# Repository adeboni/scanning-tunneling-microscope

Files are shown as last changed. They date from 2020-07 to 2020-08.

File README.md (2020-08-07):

# Home-made scanning tunneling microscope

This repository contains schematics I made in order to fully build Dan Berard's STM implementation, based on John Alexander's STM design: https://dberard.com/home-built-stm/

## Sample scan from the STM:
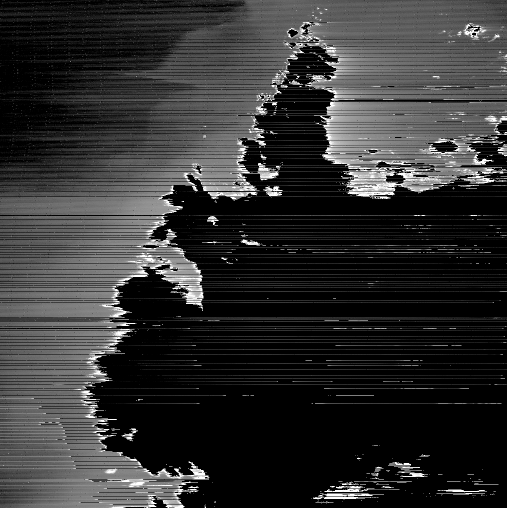
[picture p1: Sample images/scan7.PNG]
Sample scan


## Pictures of the STM:
Device photo 1
Device photo 2

## SEM image of the probe tip:
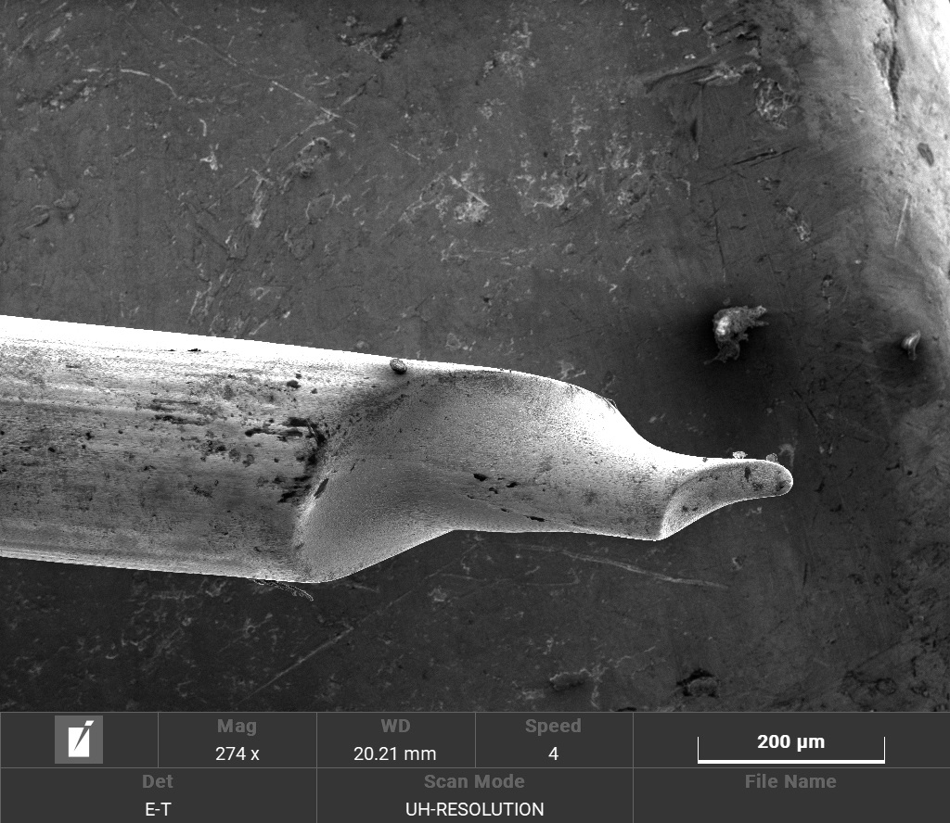
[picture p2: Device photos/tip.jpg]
Tip


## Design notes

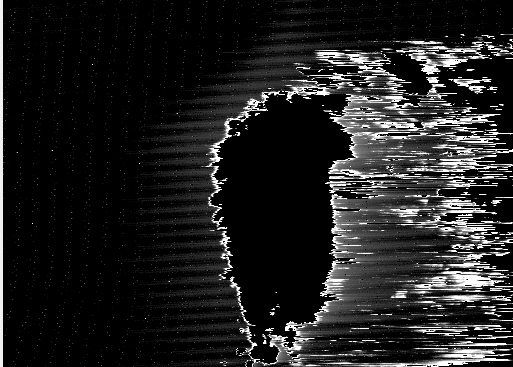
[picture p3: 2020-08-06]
Sample images/scan4.PNG

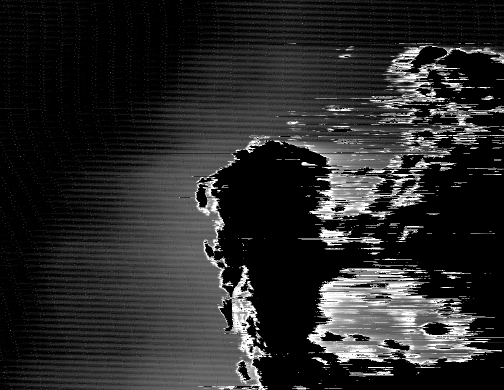
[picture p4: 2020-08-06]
Sample images/scan5.PNG

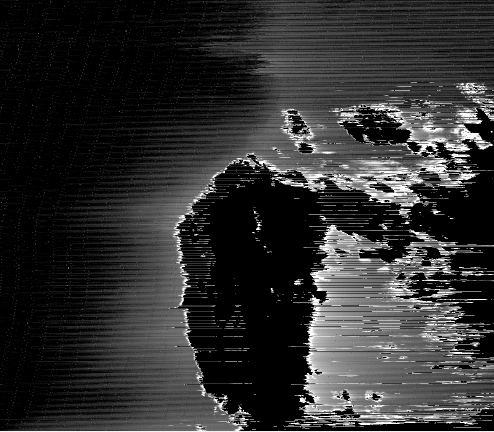
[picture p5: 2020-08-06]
Sample images/scan6.PNG

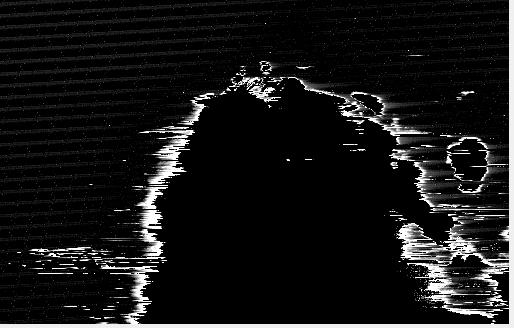
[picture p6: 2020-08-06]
Sample images/scan3.PNG

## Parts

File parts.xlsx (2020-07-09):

Qty | Part | Value | Package | Unit Cost | Total Cost
Microcontroller Board
1 | PCB |  |  | $2.00 | $2.00
1 | Teensy 3.2 |  |  | $15.00 | $15.00
2 | Pin Socket | 1x7 |  | $3.00 | $6.00
1 | 2x13 IDC Connector |  |  | $3.00 | $3.00
2 | LED |  | 5mm | $0.20 | $0.40
2 | Resistor | 120 | Axial | $0.10 | $0.20
Power Supply
1 | PCB |  |  | $2.00 | $2.00
1 | Barrel Jack |  | 2.1mm | $0.40 | $0.40
1 | Linear Regulator | 7815 | TO220 | $2.50 | $2.50
1 | Linear Regulator | 7915 | TO220 | $2.50 | $2.50
1 | Linear Regulator | LM1117-3.3 | TO220 | $2.50 | $2.50
1 | Switching Regulator | R-78E5.0-0.5 | WE78 | $2.50 | $2.50
6 | Rectifier Diode | 1N4004 | Axial | $0.20 | $1.20
4 | Electrolytic Capacitor | 3300u | Radial 18mm | $2.00 | $8.00
2 | Electrolytic Capacitor | 10u | Radial 6mm | $0.20 | $0.40
8 | Ceramic Capacitor | 1u | Radial 2.5mm | $0.60 | $4.80
2 | Resistor | 2.4k | Axial | $0.20 | $0.40
1 | Pin Header | 1x5 |  | $0.20 | $0.20
1 | AC-AC Adapter | 15VAC |  | $15.00 | $15.00
1 | Enclosure |  |  | $10.00 | $10.00
Transimpedance Amplifier
1 | PCB |  |  | $2.00 | $2.00
2 | Tantalum Capacitor | 4.7u | 2512 | $2.50 | $5.00
2 | Ceramic Capacitor | 100n | 0805 | $0.10 | $0.20
1 | Op Amp | OPA124 | SOIC8 | $15.00 | $15.00
1 | Teflon Standoff | Keystone 11301 |  | $2.00 | $2.00
1 | Resistor | 100M | Axial | $5.00 | $5.00
1 | Resistor | 220 | 0805 | $0.10 | $0.10
Analog Board
1 | PCB |  |  | $7.00 | $7.00
1 | Tantalum Capacitor | 100u | 7343 | $2.50 | $2.50
9 | Tantalum Capacitor | 10u | 3528 | $0.50 | $4.50
6 | Tantalum Capacitor | 10u | 0805 | $0.50 | $3.00
33 | Ceramic Capacitor | 100n | 0805 | $0.10 | $3.30
10 | Ceramic Capacitor | 4.7n | 0805 | $0.20 | $2.00
1 | Ceramic Capacitor | 2.2u | 1206 | $0.30 | $0.30
8 | Ceramic Capacitor | 3.3n | 0805 | $0.10 | $0.80
1 | Ceramic Capacitor | 47u | 1210 | $1.00 | $1.00
1 | LED |  | 0805 | $0.20 | $0.20
2 | DB9 Board Connector | Female | Through-hole | $3.00 | $6.00
2 | DB9 Cable Connector | Male |  | $1.50 | $3.00
4 | Ferrite Bead | 600 ohm | 0805 | $0.30 | $1.20
1 | 2x13 IDC Connector |  |  | $3.00 | $3.00
1 | 2x13 IDC Cable |  |  | $5.00 | $5.00
1 | Pin Header | 1x5 |  | $0.20 | $0.20
23 | Resistor | 3k | 0805 | $0.10 | $2.30
1 | Resistor | 1k | 0805 | $0.10 | $0.10
4 | Resistor | 220 | 0805 | $0.10 | $0.40
4 | Resistor | 1.5k | 0805 | $0.10 | $0.40
2 | Resistor | 10k | 0805 | $0.10 | $0.20
1 | Resistor | 30k | 0805 | $0.10 | $0.10
4 | Resistor | 470 | 0805 | $0.10 | $0.40
1 | Resistor | 100 | 0805 | $0.10 | $0.10
3 | Op Amp | OPA2227U | SOIC8 | $10.00 | $30.00
1 | Voltage Reference | REF102AU | SOIC8 | $6.00 | $6.00
2 | Op Amp | OPA4227 | SOIC14 | $12.00 | $24.00
1 | DAC | DAC8814 | SSOP28 | $40.00 | $40.00
1 | ADC | LTC2326 | MSOP16 | $33.00 | $33.00
1 | Op Amp | LT1469 | SOIC8 | $15.00 | $15.00
1 | Enclosure |  |  | $15.00 | $15.00
Scan Head
1 | Piezo | 6.3Khz | 20mm | $0.70 | $0.70
1 | Sapphire Crystal | 16mm |  | $7.00 | $7.00
1 | Tungsten Wire Roll | 30 AWG |  | $10.00 | $10.00
1 | Aluminum Standoff |  | 3mm x 10mm | $0.50 | $0.50
3 | Fine Adjustment Screws | 1/4-80 |  | $9.00 | $27.00
3 | Bushings | 1/4-80 |  | $9.00 | $27.00
2 | Aluminum Block |  | 0.5" x 2" x 2" | $2.00 | $4.00
4 | Screw |  | 0.5" long | $0.10 | $0.40
2 | Spring |  | 1" long | $0.50 | $1.00
1 | Copper Tape |  |  | $10.00 | $10.00
1 | Pin Header | 1x5 |  | $0.20 | $0.20
1 | Enameled Wire | 40 AWG |  | $10.00 | $10.00
2 | Neodymium magnet |  | 10mm | $0.50 | $1.00
Anti-Vibration Base
3 | Extension Springs |  | 2 ft long | $5.00 | $15.00
1 | MDF Board |  | 2 ft x 2 ft | $10.00 | $10.00
3 | Round Steel Plate |  | 0.5" x 5" | $7.00 | $21.00
1 | Round Aluminum Plate |  | 0.5" x 6" | $20.00 | $20.00
3 | Viton FKM O-Rings |  |  | $2.00 | $6.00
12 | Hard Drive Magnets |  |  | $0.50 | $6.00
3 | Eye Bolts | 3/8" | 5" long | $2.00 | $6.00
3 | Eye Bolts | 3/8" | 1" long | $2.00 | $6.00
3 | Threaded Rod | 3/8" | 3 ft long | $4.00 | $12.00
3 | Rubber Feet Stickers |  | 5mm | $0.50 | $1.50
21 | Nuts | 3/8" |  | $0.10 | $2.10
 |  |  |  | Total | $522.70

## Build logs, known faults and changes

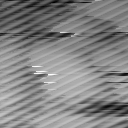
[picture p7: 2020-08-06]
Dan Berard's stuff/PC software/STM/bin/Debug/scan.tiff

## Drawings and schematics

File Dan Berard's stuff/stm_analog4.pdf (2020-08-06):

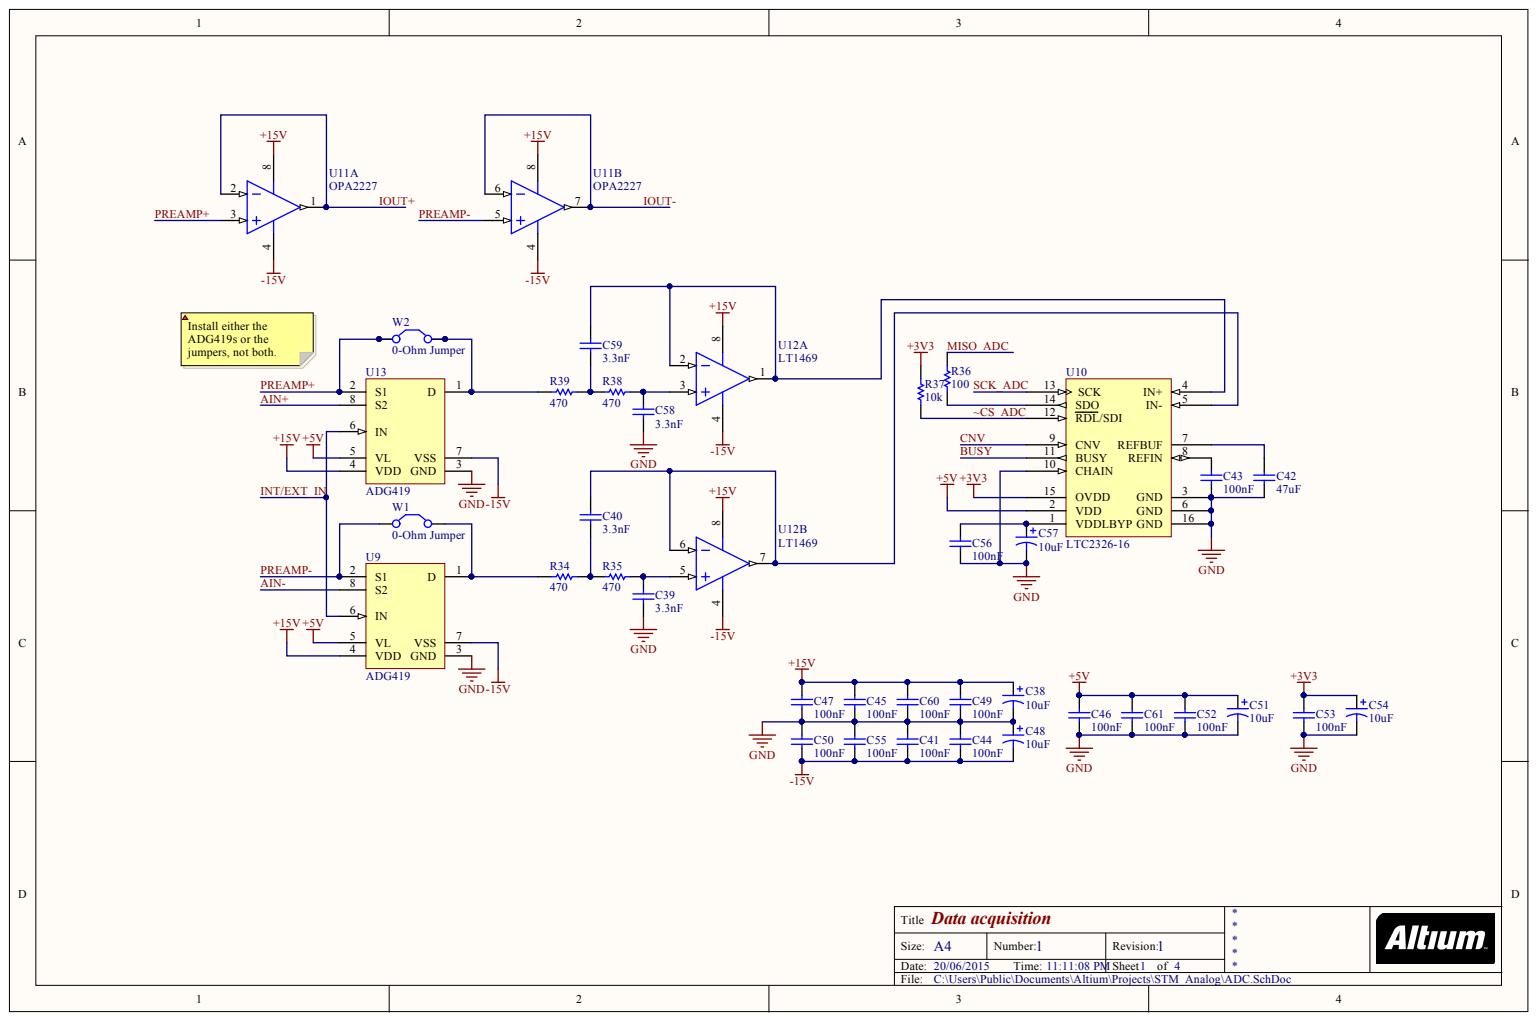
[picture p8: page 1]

Data acquisition Title | * * * * *

Size: A4 | Number: 1 | Revision: 1
Date: 20/06/2015 Time: 11:11:08 PM | | Sheet of 4

C:\Users\Public\Documents\Altium\Projects\STM_Analog\ADC.SchDoc
File:

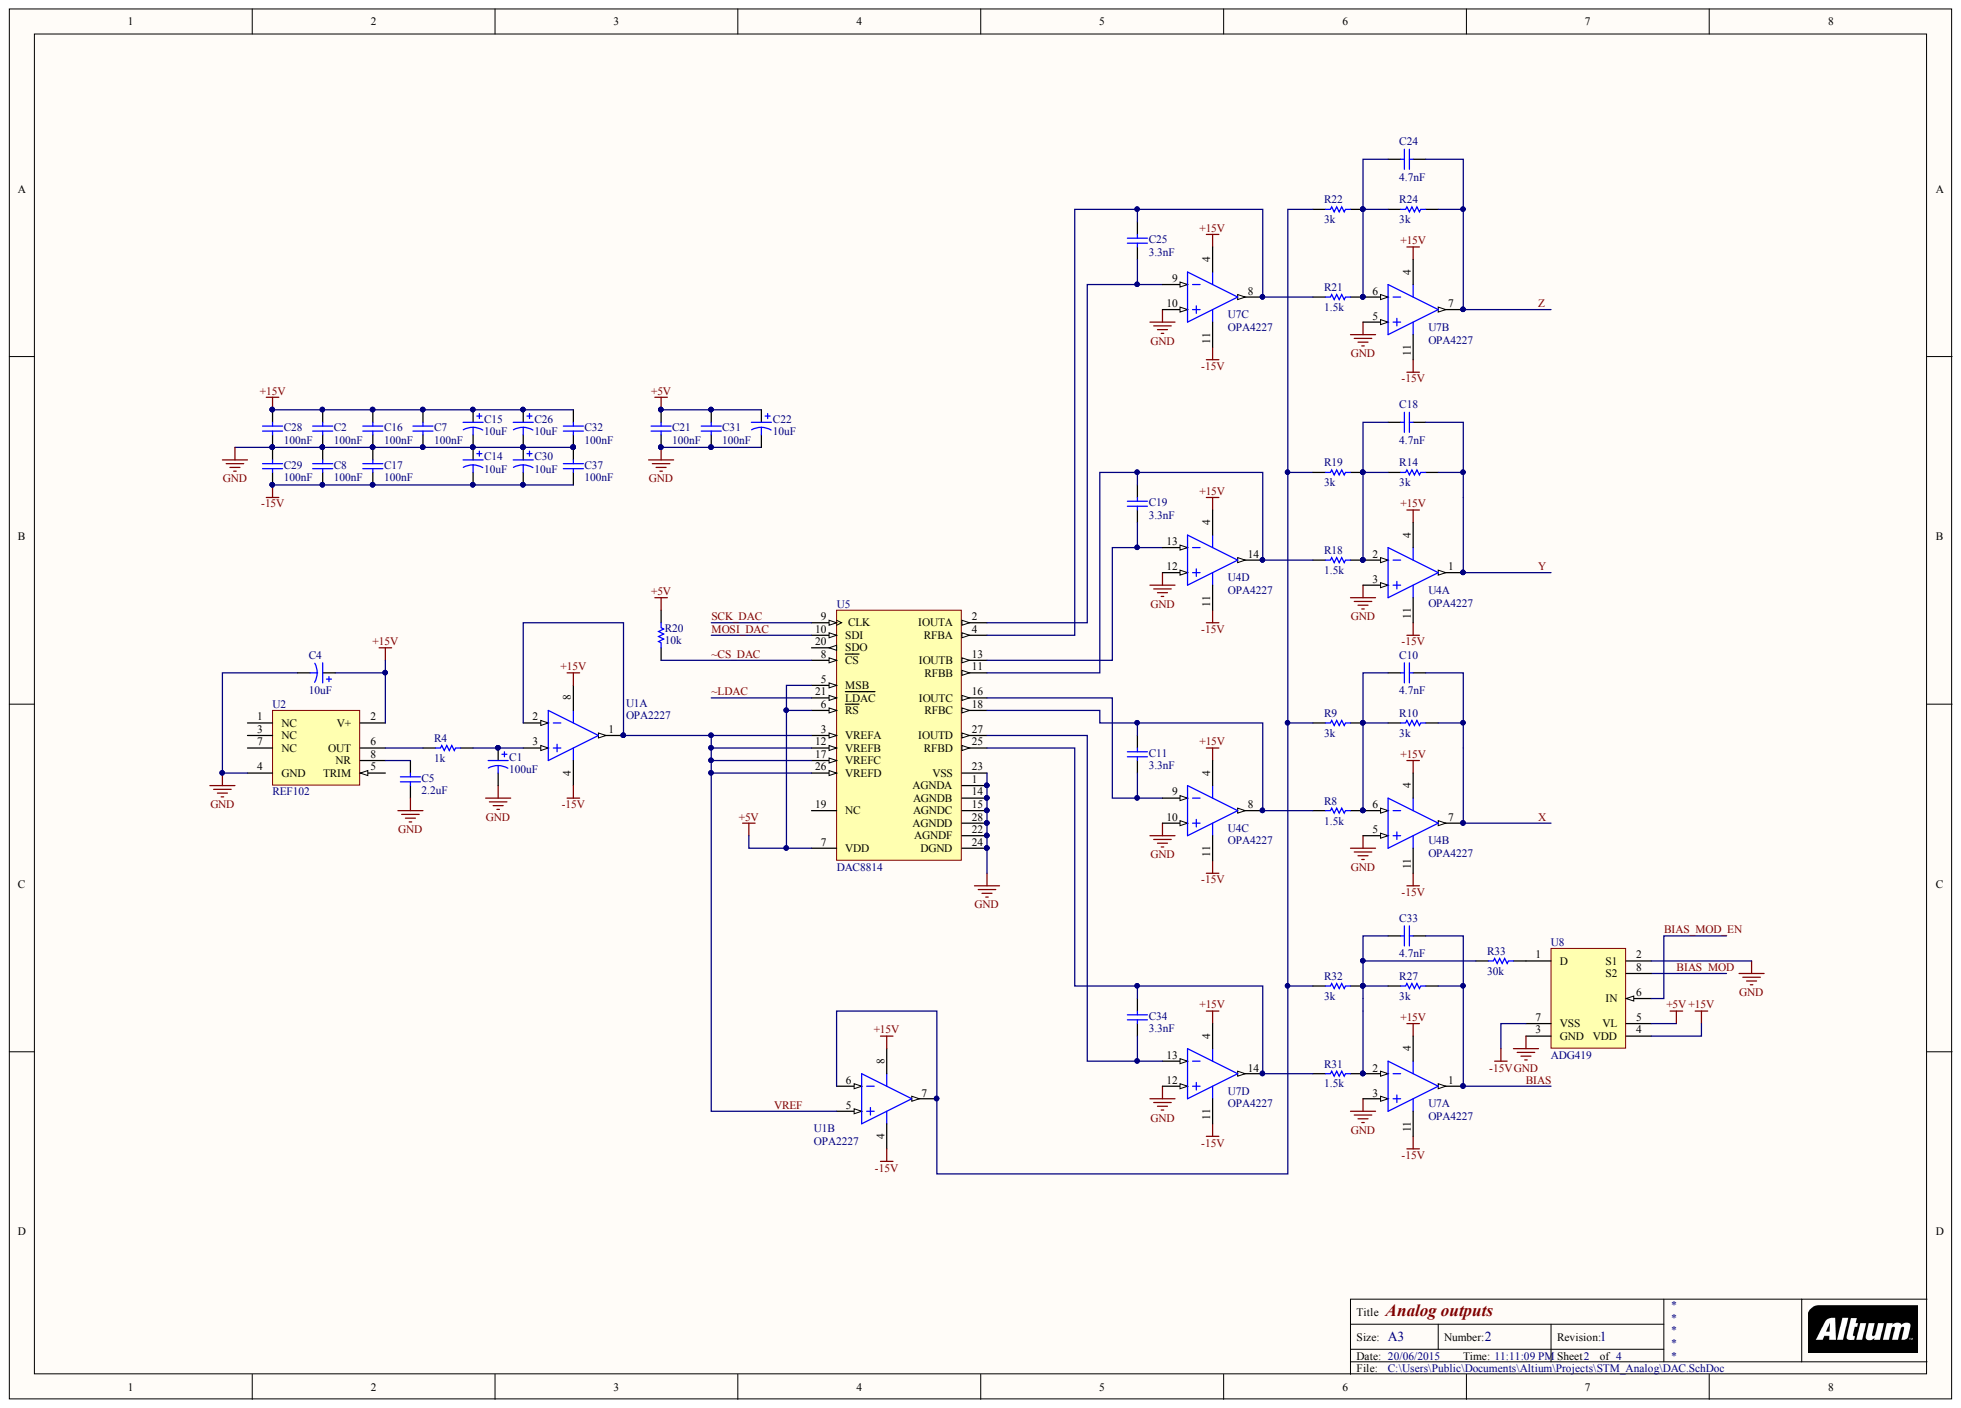
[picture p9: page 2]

Analog ou tpu T i t l e | **** *

Size: A | Number : | Revi s ion:

T i me: | | Sheet of

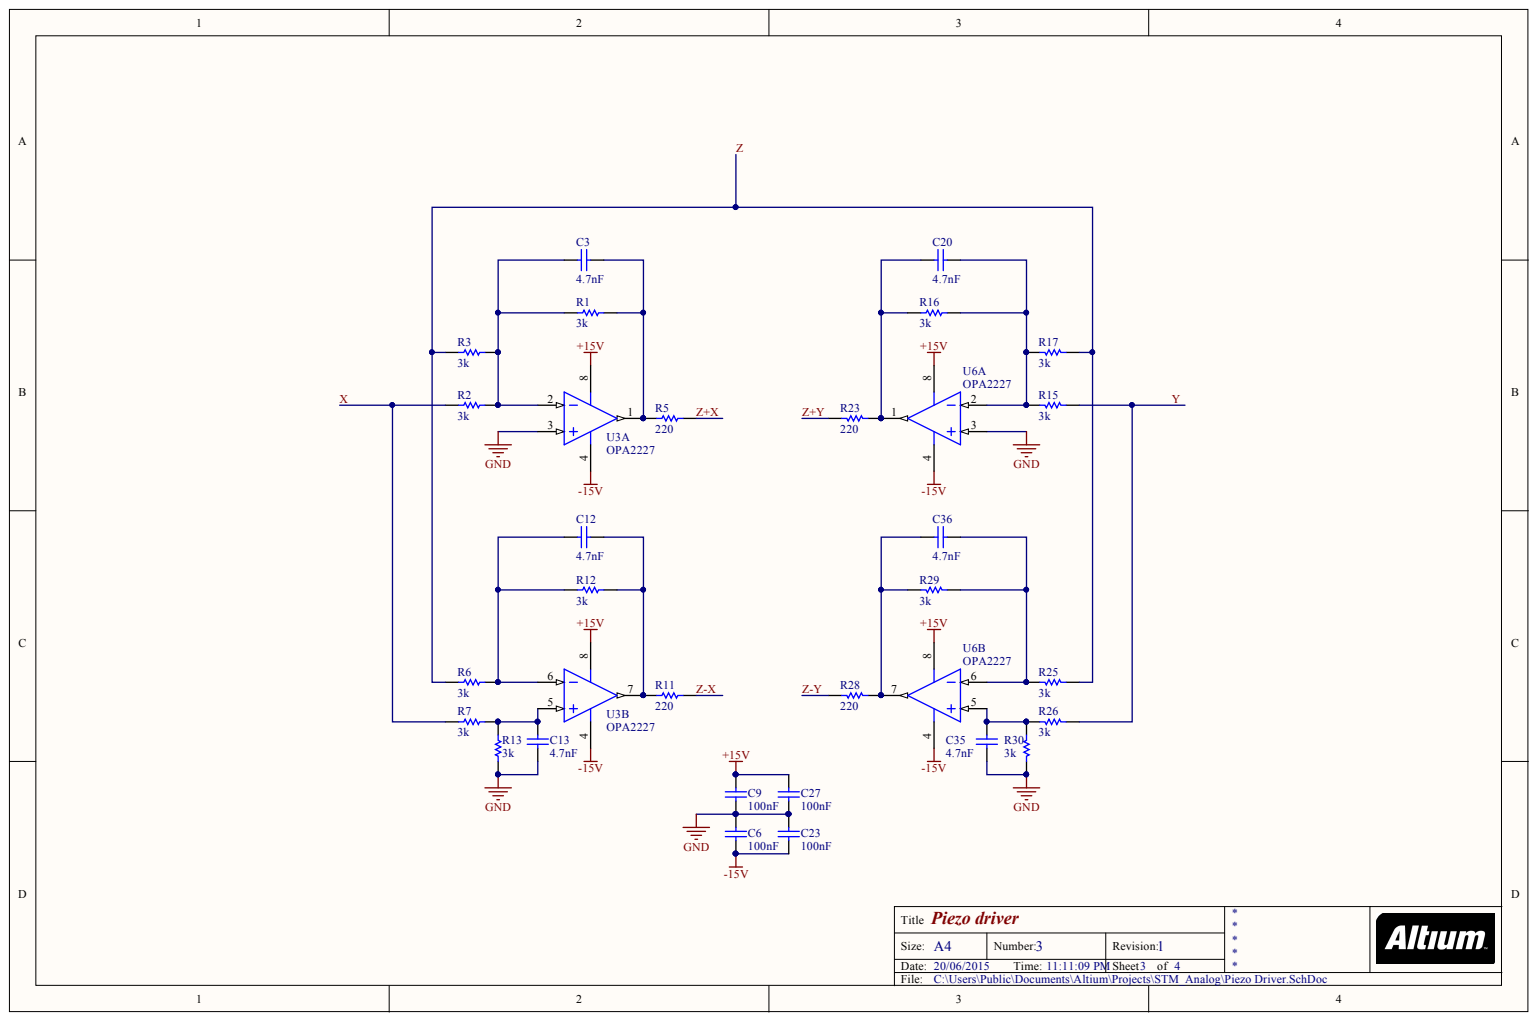
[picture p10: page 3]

Piezo driver Title | * * * * *

Size: A4 | Number: 3 | Revision: 1
20/06/2015 Time: 11:11:09 PM | | Sheet of 4

C:\Users\Public\Documents\Altium\Projects\STM_Analog\Piezo Driver.SchDoc
File:

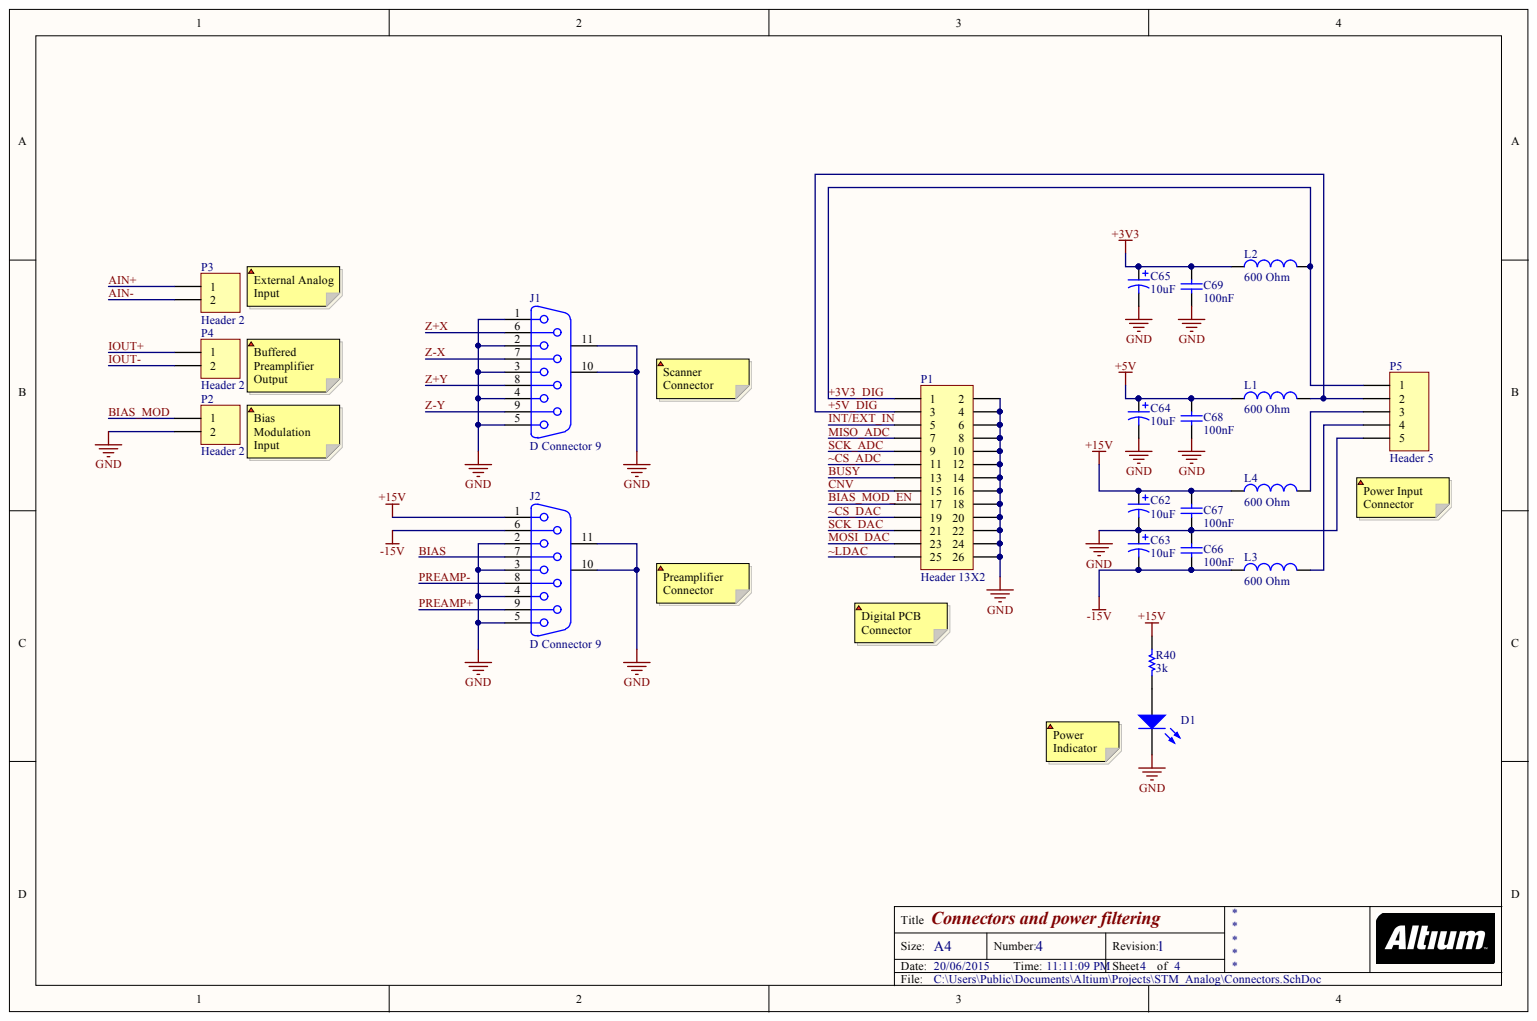
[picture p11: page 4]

Connectors and p ower filtering T i t l e | **** *

Size: A4 | N umber: 4 | Rev i s i o n : 1

/ / T ime: : : 9 PM | | Sheet o f

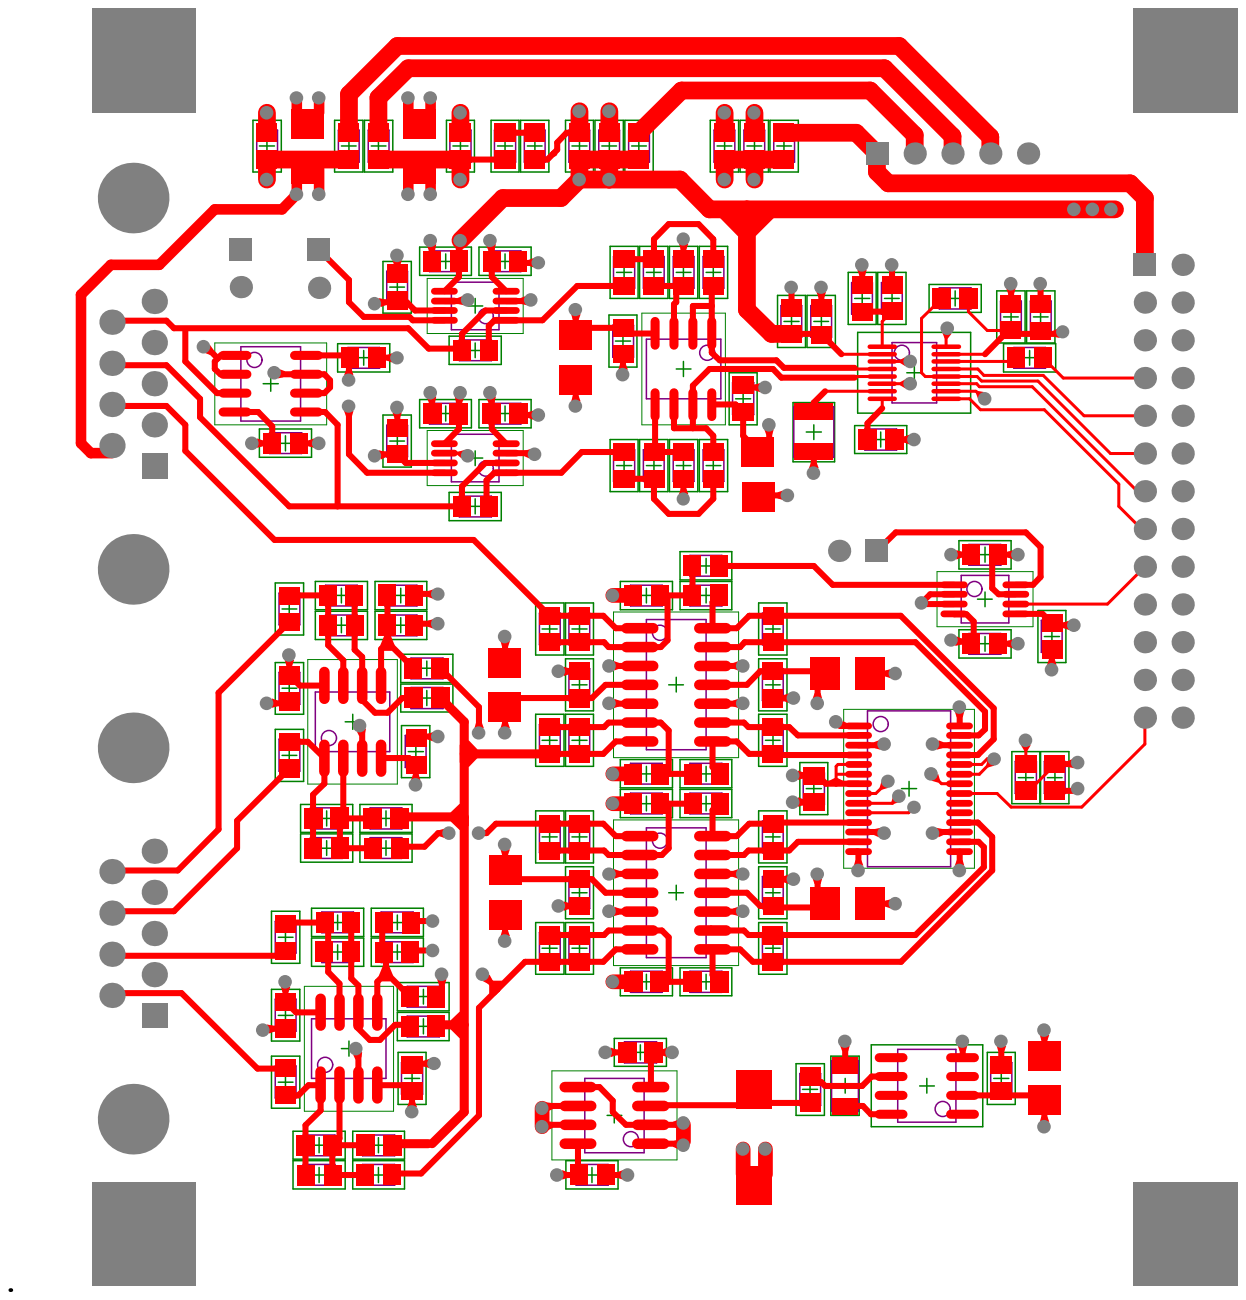
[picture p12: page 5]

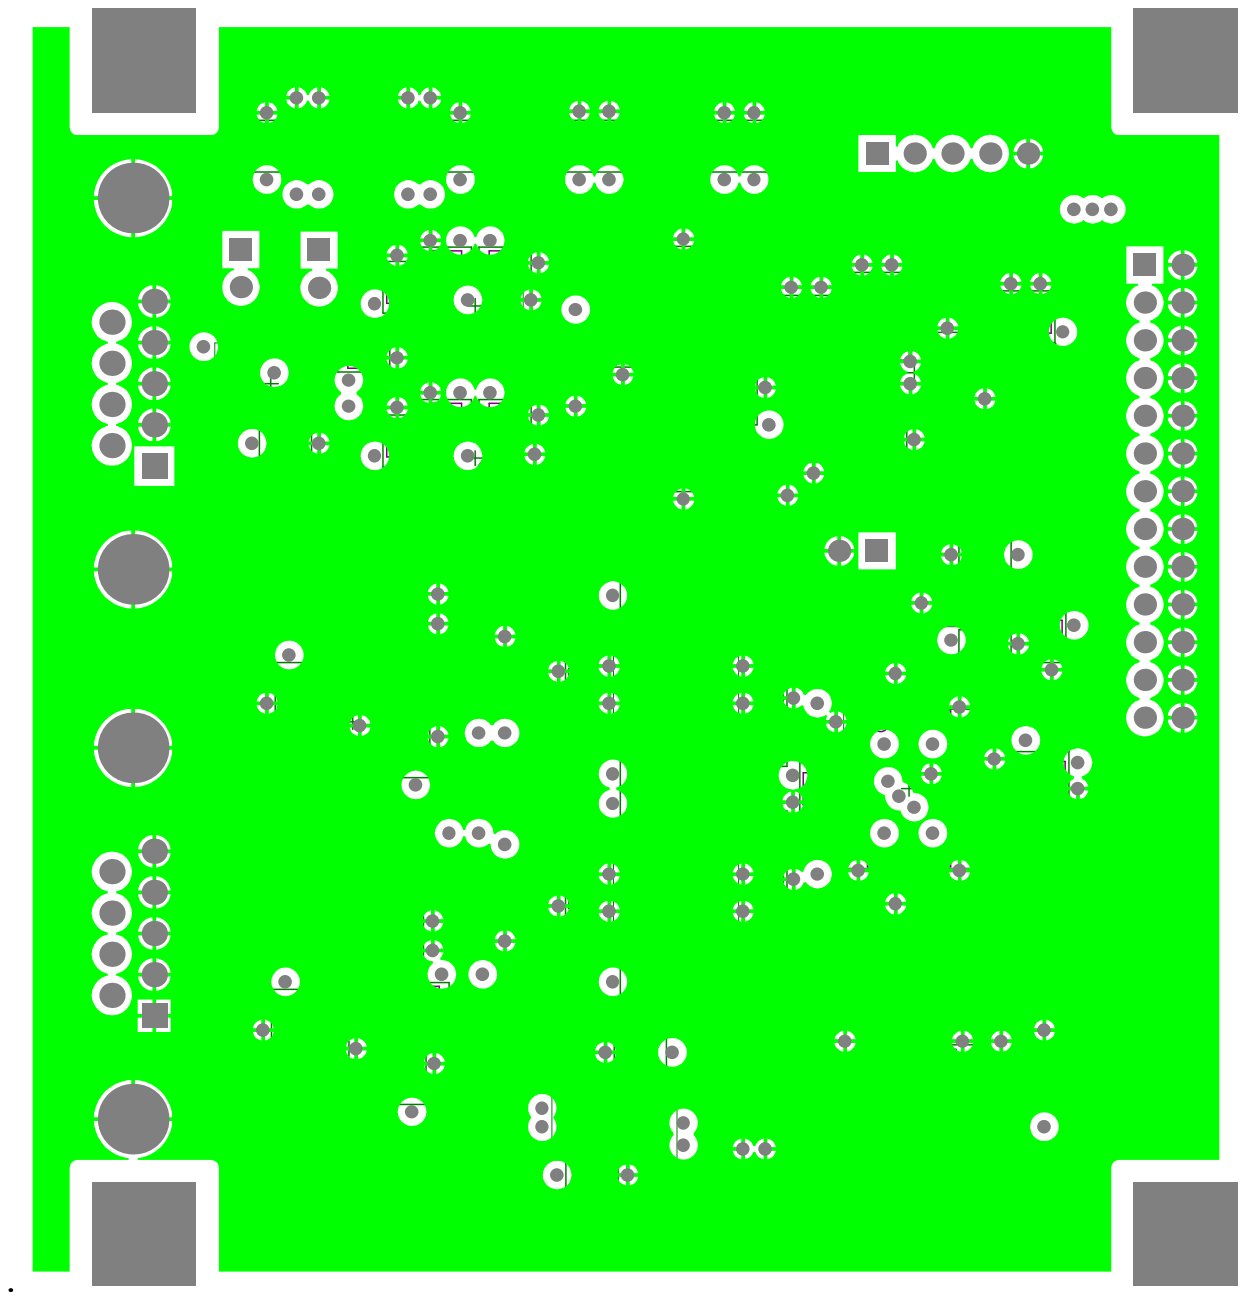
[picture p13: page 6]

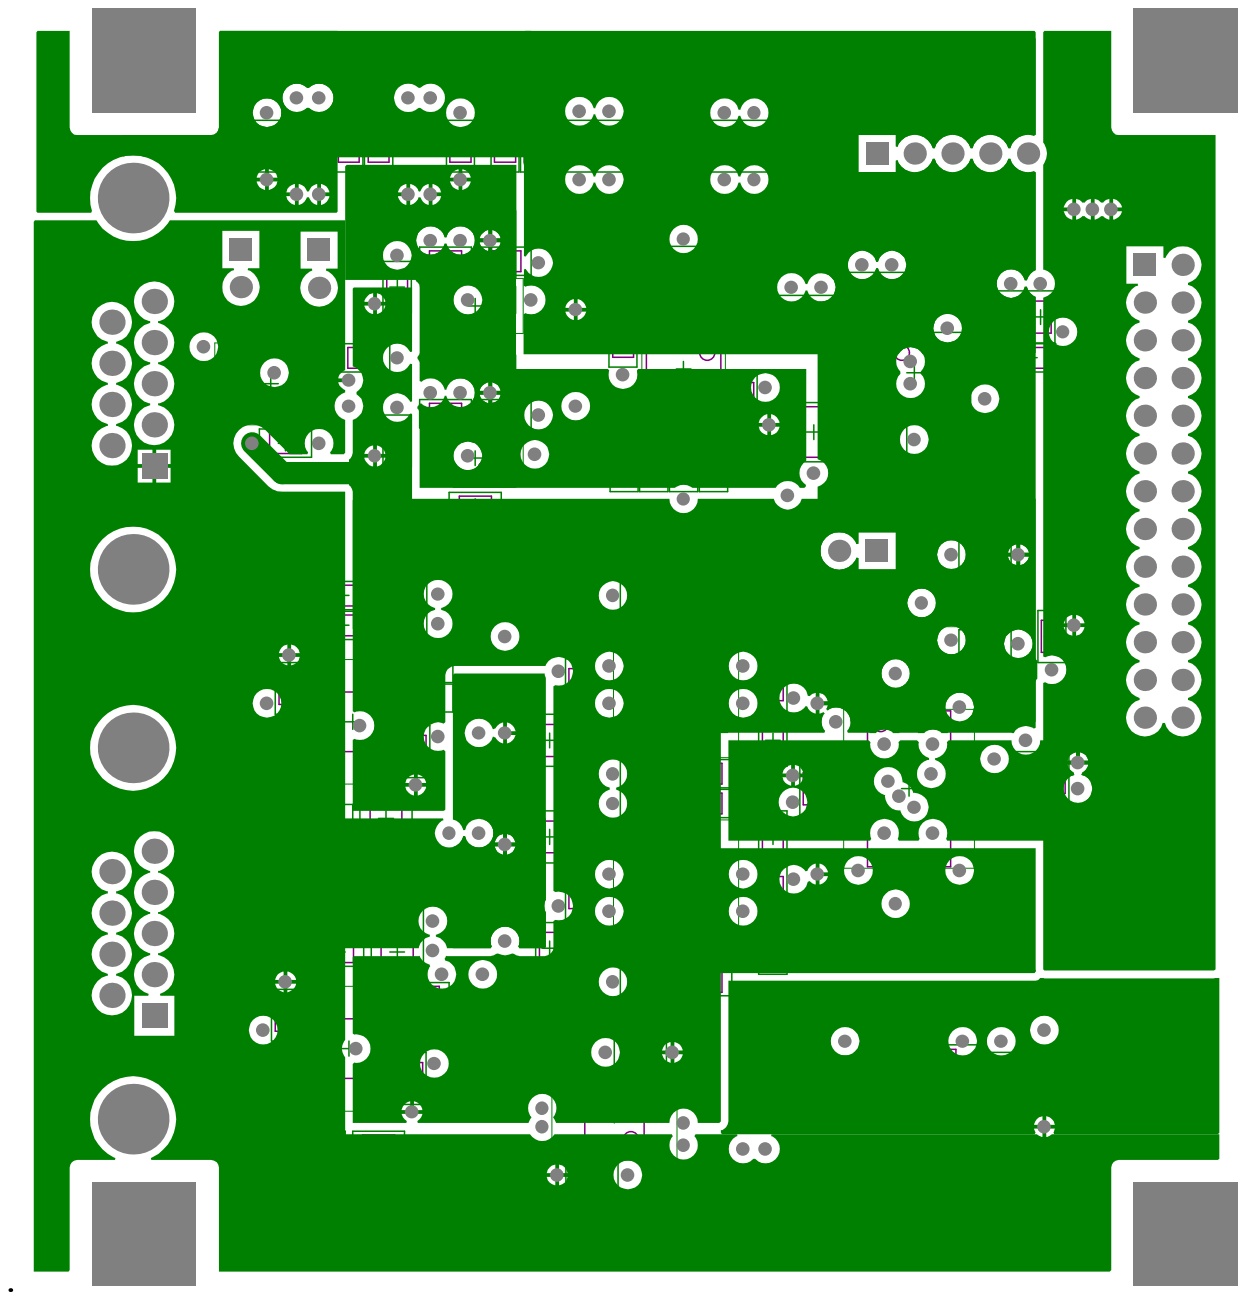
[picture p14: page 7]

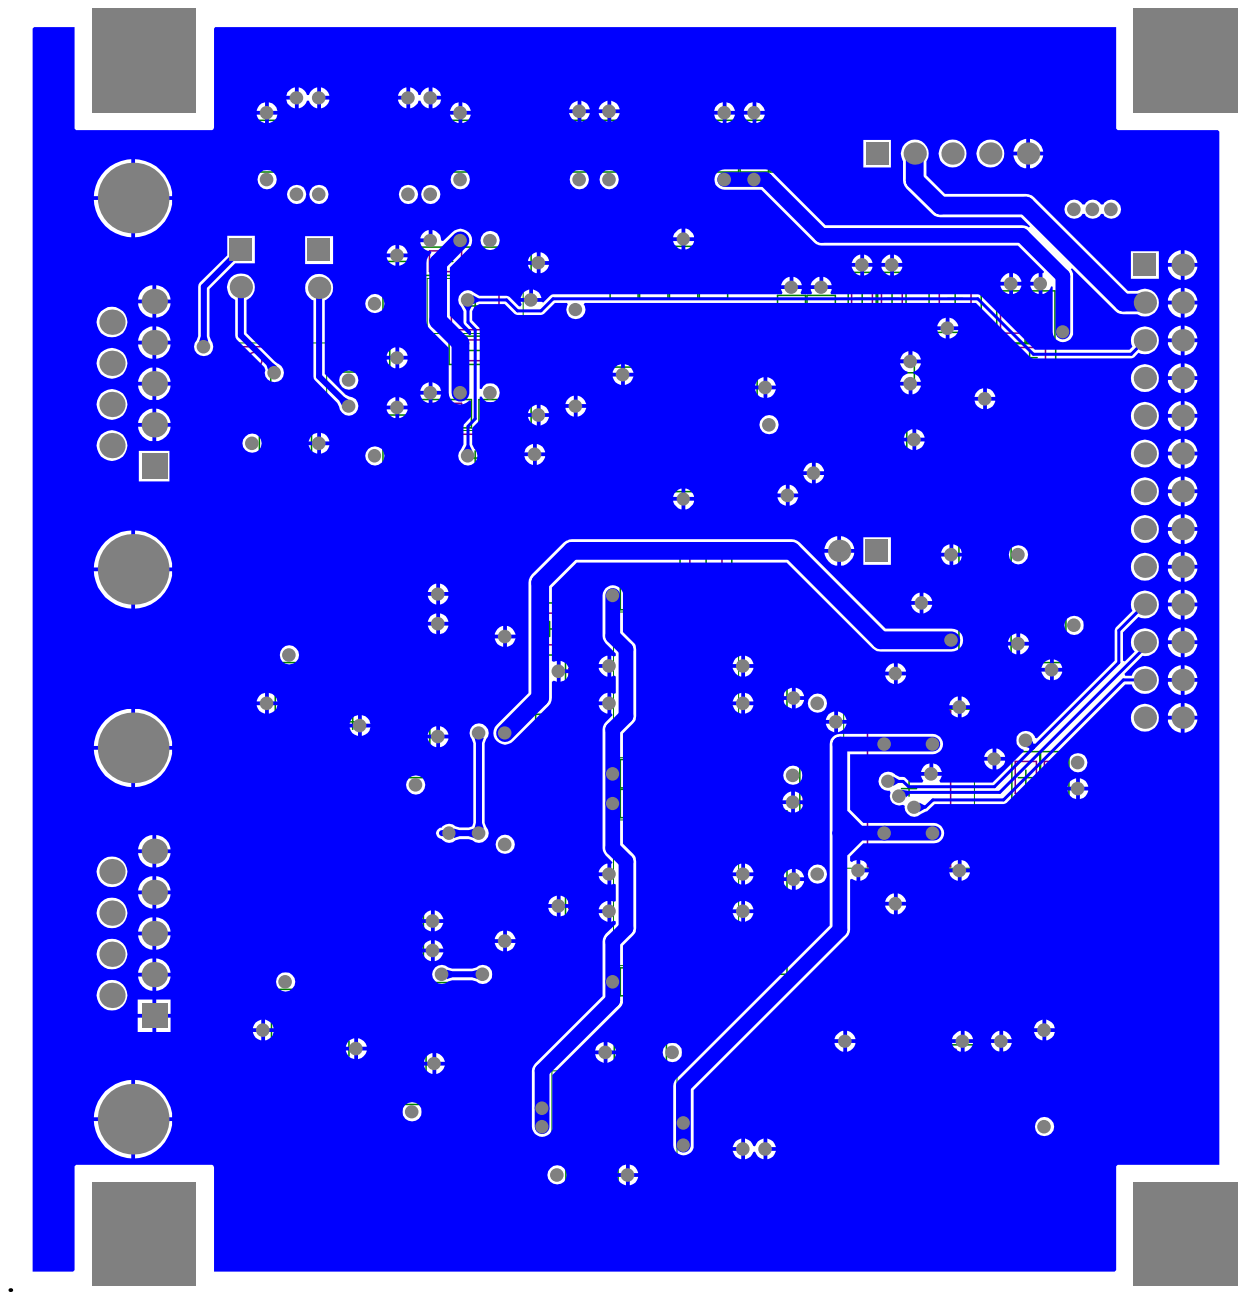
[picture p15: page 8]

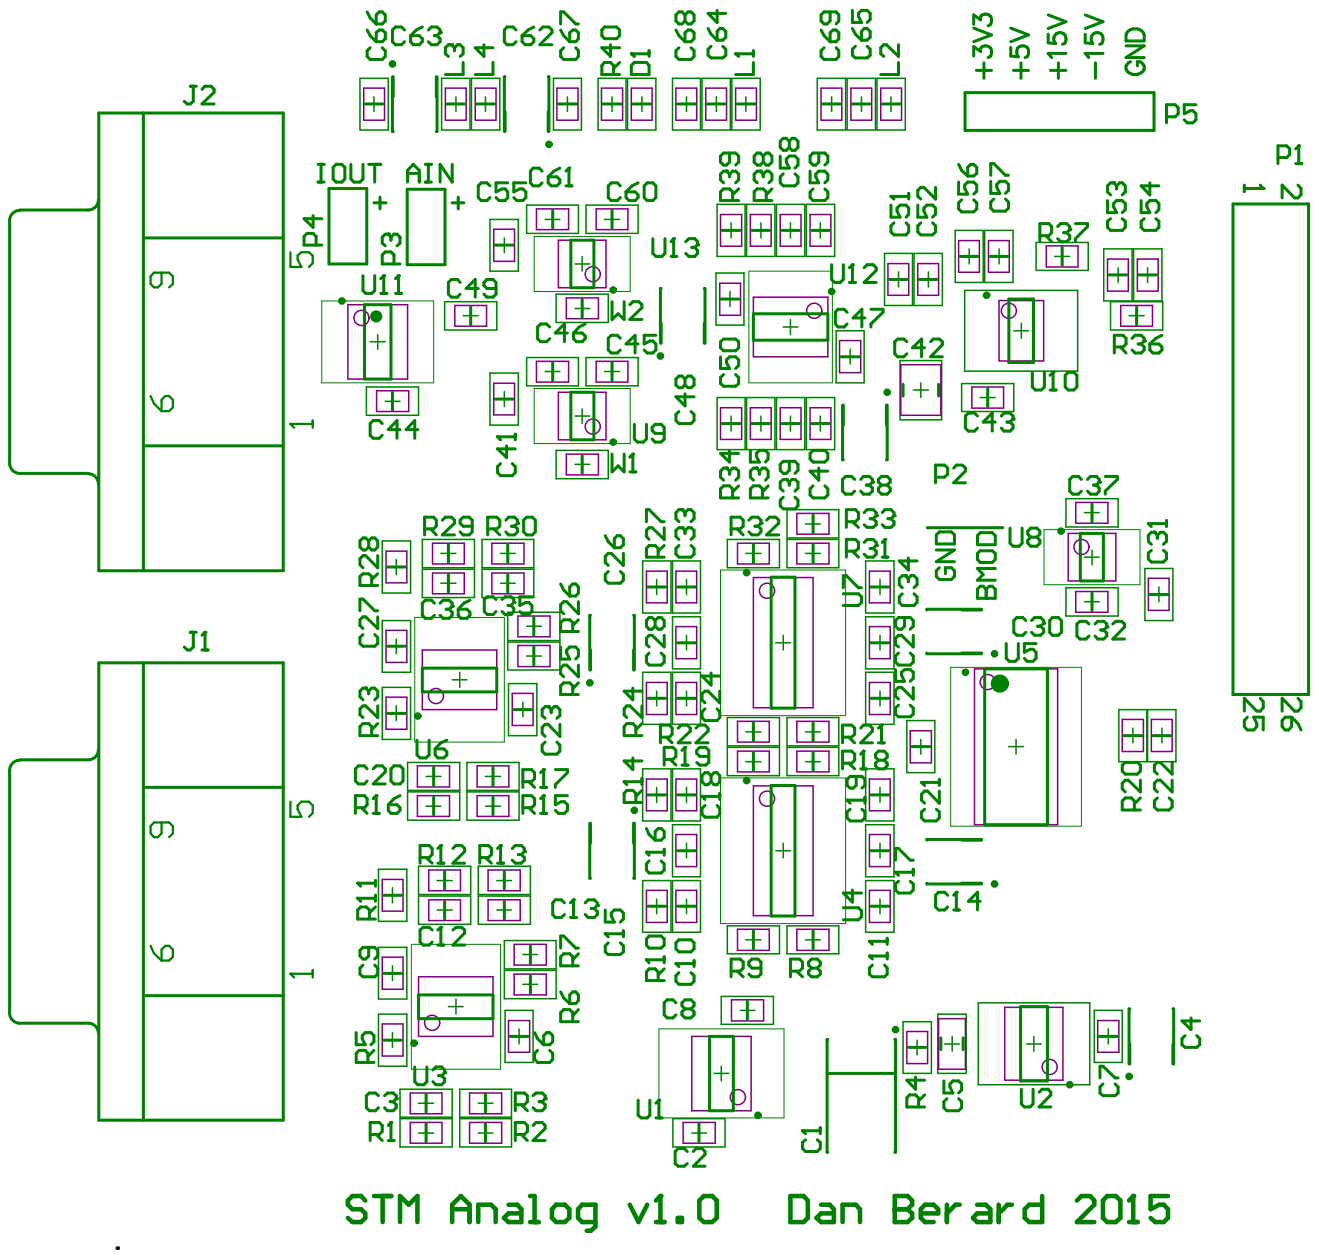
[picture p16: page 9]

Bill of Materials | Bill of Materials For Project [STM_Analog.PrjPcb] (No PCB Document Selected)
Source Data From: | STM_Analog.PrjPcb
Project: | | STM_Analog.PrjPcb
Variant: | | None
Creation Date: 20/06/2015 | 11:11:17 PM
Print Date: | 20-Jun-15 | 11:11:37 PM
Footprint | Comment | LibRef | Designator | Description | Quantity
7343 | 100uF | Cap Pol1 | C1 | Polarized Capacitor (Radial) | 1
6-0805_N | 100nF | Cap | C2, C6, C7, C8, C9, C16, C17, C21, C23,
| | | C27, C28, C29, C31, C32, C37, C41, C43,
| | | C44, C45, C46, C47, C49, C50, C52, C53,
| | | C55, C56, C60, C61, C66, C67, C68, C69 | Capacitor | 33
6-0805_N | 4.7nF | Cap | C3, C10, C12, C13, C18, C20, C24, C33,
| | | C35, C36 | Capacitor | 10
3528 | 10uF | Cap Pol1 | C4, C14, C15, C26, C30, C38, C48, C62,
| | | C63 | Polarized Capacitor (Radial) | 9
C1206 | 2.2uF | Cap | C5 | Capacitor | 1
6-0805_N | 3.3nF | Cap | C11, C19, C25, C34, C39, C40, C58, C59 | Capacitor | 8
6-0805_N | 10uF | Cap Pol1 | C22, C51, C54, C57, C64, C65 | Polarized Capacitor (Radial) | 6
C1210 | 47uF | Cap | C42 | Capacitor | 1
6-0805_N | | LED0 | D1 | Typical INFRARED GaAs LED | 1
DSUB1.385- 2H9 | D Connector 9 | D Connector 9 | J1, J2 | Receptacle Assembly, 9 Position, Right
| | | | Angle | 2
6-0805_N | 600 Ohm | Inductor | L1, L2, L3, L4 | Inductor | 4
HDR2X13 | Header 13X2 | Header 13X2 | P1 | Header, 13-Pin, Dual row | 1
HDR1X2 | Header 2 | Header 2 | P2, P3, P4 | Header, 2-Pin | 3
HDR1X5 | Header 5 | Header 5 | P5 | Header, 5-Pin | 1
6-0805_N | 3k | Res1 | R1, R2, R3, R6, R7, R9, R10, R12, R13,
| | | R14, R15, R16, R17, R19, R22, R24, R25,
| | | R26, R27, R29, R30, R32, R40 | Resistor | 23
6-0805_N | 1k | Res1 | R4 | Resistor | 1
6-0805_N | 220 | Res1 | R5, R11, R23, R28 | Resistor | 4
6-0805_N | 1.5k | Res1 | R8, R18, R21, R31 | Resistor | 4
6-0805_N | 10k | Res1 | R20, R37 | Resistor | 2
6-0805_N | 30k | Res1 | R33 | Resistor | 1
6-0805_N | 470 | Res1 | R34, R35, R38, R39 | Resistor | 4
6-0805_N | 100 | Res1 | R36 | Resistor | 1
ADI-R-8_M | OPA2227 | CMP-0384-
| | 01147-2 | U1, U3, U6 | Double Channel Wide Bandwidth
| | | | Operational Amplifier, 10 MHz BW, 2.5
| | | | V/us SR, Industrial, 8-pin SOIC (R-8), Tube | 3
182H_N | REF102 | REF102AU | U2 | Precision Voltage Reference | 1
TI-D14_M | OPA4227 | CMP-0272-
| | 00152-2 | U4, U7 | High Precision, Low Noise Operational
| | | | Amplifier, 5 to 36 V, -40 to 85 degC, 14-pin
| | | | SOIC (D14), Green (RoHS & no Sb/Br) | 2
TI-DB28_L | DAC8814 | CMP-0004- 00286-1
U5 | 16-Bit, Quad, Serial Input Multiplying
Digital to Analog Converter, -40 to 85 degC, 28-pin SOP (DB28), Green (RoHS & no Sb/Br)

1

ADI-RM-8_N | ADG419 | CMP-0792- 00196-1
U8, U9, U13 | LC2MOS Precision Mini-DIP Analog
Switches, 25 Ohm Ron, 8-pin SOP (RM-8), Tube

3

MSOP-16 | LTC2326-16 | LTC2326-16 | U10 | 1
TI-D8_N | OPA2227 | CMP-0272-
| | 00267-2
U11 | High Precision, Low Noise Operational
Amplifier, 5 to 36 V, -40 to 85 degC, 8-pin SOIC (D8), Green (RoHS & no Sb/Br)
| | | | 1
LT-S8-8_N | LT1469 | CMP-0359- 02956-2
U12 | Dual Channel, 16-Bit Accurate Operational
Amplifier, 200 MHz Typical GBW, 30 V/us Typical SR, 10 to 36 V, 8-Pin SOIC (S8-8), Commercial, Pb-Free

1

6-0805_N | 0-Ohm Jumper | Jumper | W1, W2 | Jumper Wire | 2
| | | | | 136
Approved | | Notes

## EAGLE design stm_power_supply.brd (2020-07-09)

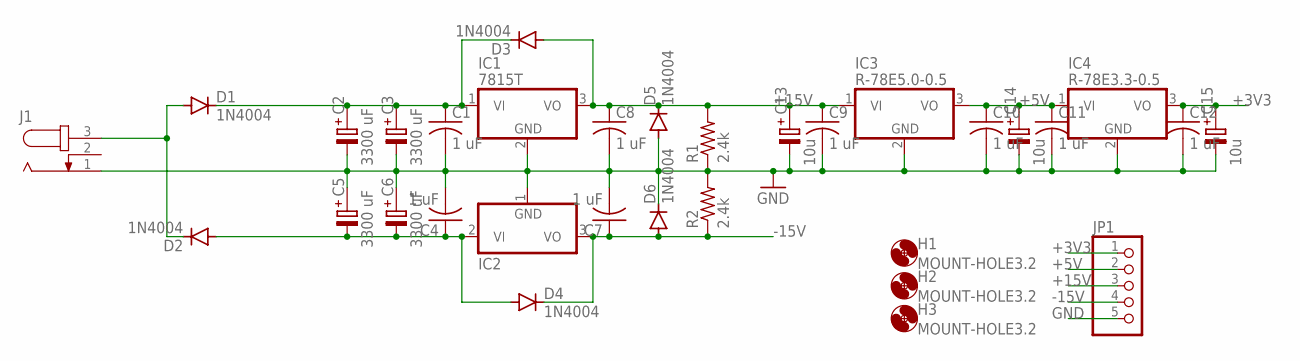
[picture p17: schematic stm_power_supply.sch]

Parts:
C1, C4, C7, C8, C9, C10, C11, C12: 1 uF; C025-024X044
C2, C3, C5, C6: 3300 uF; E7,5-18
C13, C14, C15: 10u; E2,5-6
D1, D2, D3, D4, D5, D6: 1N4004; DO41-10
H1, H2, H3: MOUNT-HOLE3.2; 3,2
IC1: 7815T; TO220H
IC2: 7915T; TO220H
IC3: R-78E5.0-0.5; WE78
IC4: R-78E3.3-0.5; WE78
J1: JACK-PLUG0; SPC4077
JP1: PINHD-1X5; 1X05
R1, R2: 2.4k; 0204/7

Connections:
+3V3: C12.1, C15.+, IC4.3 (VO), JP1.1
+5V: C10.1, C11.1, C14.+, IC3.3 (VO), IC4.1 (VI), JP1.2
+15V: C8.1, C9.1, C13.+, D3.A, D5.C, IC1.3 (VO), IC3.1 (VI), JP1.3, R1.2
-15V: C7.1, D4.C, D6.A, IC2.3 (VO), JP1.4, R2.1
GND: C1.2, C2.-, C3.-, C4.2, C5.+, C6.+, C7.2, C8.2, C9.2, C10.2, C11.2, C12.2, C13.-, C14.-, C15.-, D5.A, D6.C, IC1.2 (GND), IC2.1 (GND), IC3.2 (GND), IC4.2 (GND), J1.1, JP1.5, R1.1, R2.2
unnamed: C1.1, C2.+, C3.+, D1.C, D3.C, IC1.1 (VI)
unnamed: D1.A, D2.C, J1.3
unnamed: C4.1, C5.-, C6.-, D2.A, D4.A, IC2.2 (VI)

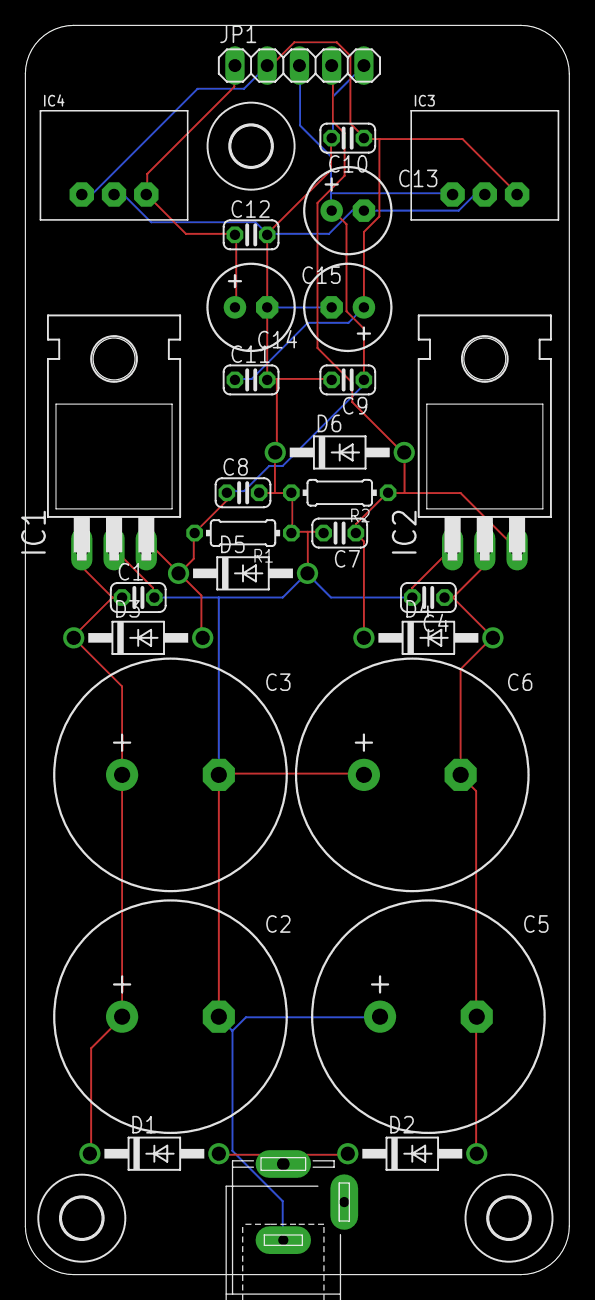
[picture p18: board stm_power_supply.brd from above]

Board: 2 copper layers, 42.9 x 98.4 mm, 32 parts (0 on the bottom side), 8 nets.

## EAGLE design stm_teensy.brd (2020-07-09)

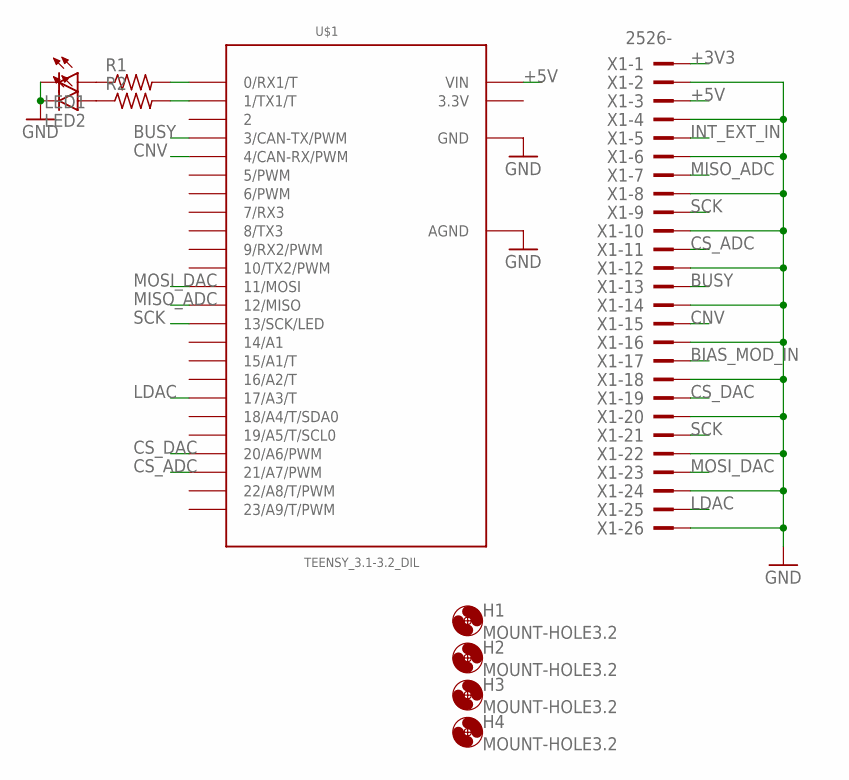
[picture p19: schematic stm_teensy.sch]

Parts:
H1, H2, H3, H4: MOUNT-HOLE3.2; 3,2
LED1, LED2: LED5MM
R1, R2: R-US_0204/7; 0204/7
U$1: TEENSY_3.1-3.2_DIL; TEENSY_3.0-3.2&LC_DIL
X1: 2526-; PAK100/2500-26

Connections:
3.3V: U$1.3.3V
+3V3: X1.1
+5V: U$1.VIN, X1.3
BIAS_MOD_IN: X1.17
BUSY: U$1.3 (3/CAN-TX/PWM), X1.13
CNV: U$1.4 (4/CAN-RX/PWM), X1.15
CS_ADC: U$1.21/A7 (21/A7/PWM), X1.11
CS_DAC: U$1.20/A6 (20/A6/PWM), X1.19
GND: LED1.K (C), LED2.K (C), U$1.AGND, U$1.GND, X1.2, X1.4, X1.6, X1.8, X1.10, X1.12, X1.14, X1.16, X1.18, X1.20, X1.22, X1.24, X1.26
INT_EXT_IN: X1.5
LDAC: U$1.17/A3 (17/A3/T), X1.25
MISO_ADC: U$1.12 (12/MISO), X1.7
MOSI_DAC: U$1.11 (11/MOSI), X1.23
unnamed: LED1.A, R1.1
unnamed: LED2.A, R2.1
unnamed: R1.2, U$1.0 (0/RX1/T)
unnamed: R2.2, U$1.1 (1/TX1/T)
SCK: U$1.13 (13/SCK/LED), X1.9, X1.21

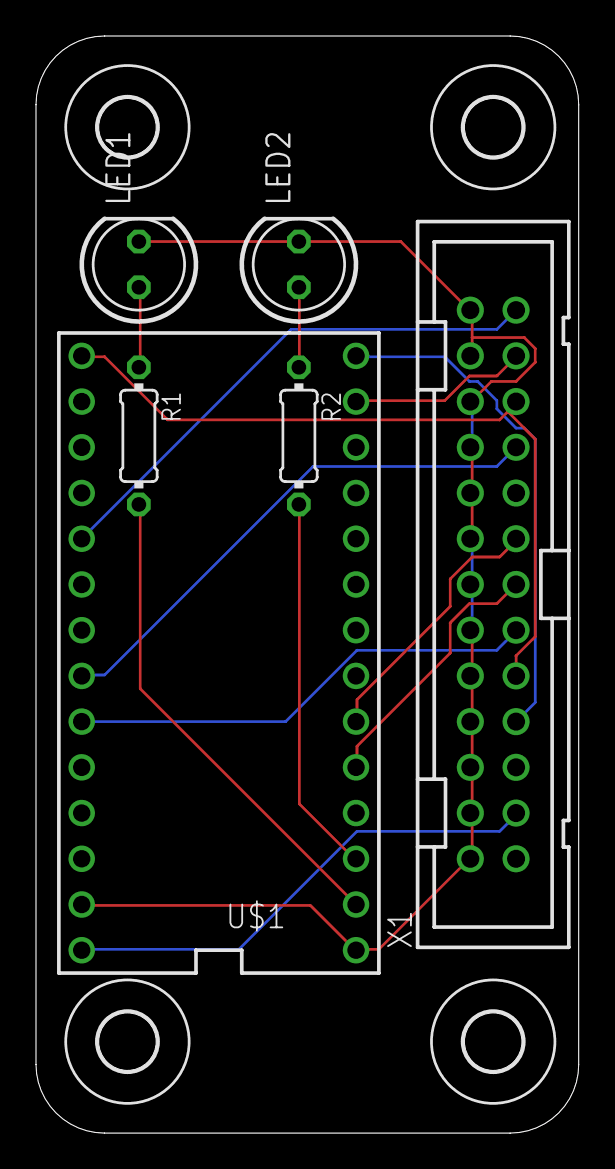
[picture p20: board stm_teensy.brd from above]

Board: 2 copper layers, 30.1 x 61.0 mm, 10 parts (0 on the bottom side), 14 nets.

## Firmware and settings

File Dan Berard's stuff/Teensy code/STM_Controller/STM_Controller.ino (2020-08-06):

/**************************************************************************/
/*

Scanning Tunneling Microscope Feedback and Scan Controller for Teensy 3.X
Last updated Oct 14, 2015
http://dberard.com/home-built-stm/


 * Copyright (c) Daniel Berard, daniel.berard@mail.mcgill.ca
 *
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

This program uses an intervalTimer to call an ISR at a time interval defined
by "dt" (see #define statements below). The ISR increments the scan, reads the 
ADC, performs PI calculations, sigma-delta calculations, updates the X, Y, and 
Z DACs and stores acquired data in buffers. Data is sent over USB when the 
scanner finishes scanning and re-scanning a line.

Set the CPU speed to 96 MHz optimized (overclock) or faster.
Cut the small trace on the bottom of the Teensy board to separate Vin from VUSB,
since the Teensy is being powered from an external 5V supply.

STM analog PCB to Teensy 3.1 connections:

All GNDs -> Teensy GND
+5V -> Vin
~CS_DAC -> pin 20
~LDAC -> pin 17
~CS_ADC -> pin 21
CNV -> pin 4
BUSY -> pin 3
MISO_ADC -> pin 12
MOSI_DAC -> pin 11
Serial indicator LED -> pin 0
Tunneling indicator LED -> pin 1
SCK_ADC and SCK_DAC -> pin 13.

*/
/**************************************************************************/


// Pin definitions:
#define CS_DAC 20                          // DAC chip select pin
#define LDAC 17                            // Load DAC pin, not currently used
#define CS_ADC 21                          // ADC chip select pin
#define CNV 4                              // ADC CNV pin - initiates a conversion
#define BUSY 3                             // ADC BUSY pin
#define SERIAL_LED 0                       // Indicates serial data transmission
#define TUNNEL_LED 1                       // Indicates tunneling


// DAC channel addresses:
#define DAC_CH_X 2
#define DAC_CH_Y 1
#define DAC_CH_Z 0
#define DAC_CH_BIAS 3


// DAC and ADC resolution:
#define DAC_BITS 16                        // Actual DAC resolution
#define POSITION_BITS 20                   // Sigma-delta resolution
#define ADC_BITS 16


// Default scan settings:
#define SCAN_SIZE 100000 // ~160 nm        // Scan size in LSBs
#define IMAGE_PIXELS 512                   // Scan size in pixels
#define LINE_RATE 1                        // Number of scan lines/second
#define SETPOINT 328 // 1 nA               // Tunneling current setpoint in LSBs
#define BIAS 328 // 100 mV                 // Sample bias in LSBs
#define KP 0                               // Proportional gain
#define KI 300000                          // Integral gain


// Constants:
#define INVERT_Z true                      // Inverts the Z output signal from the DAC
#define ENGAGE_SCANNER_STEP_SIZE 50        // Number of LSBs to step the scanner by during engage
#define ENGAGE_MOTOR_STEP_SIZE 1           // Number of steps to move the motor by during engage
#define dt 40                              // Time step for scanning and PI control in microseconds
#define DATA_BUFFER_LENGTH 16386           // Number of bytes in each ping-pong buffer for data storage. Need 2 bytes for line number + 16 bytes/pixel.
#define SCAN_COUNTER_LIMIT 0x40000000      // Scan counter counts from -SCAN_COUNTER_LIMIT to SCAN_COUNTER_LIMIT-1


/**************************************************************************/

#include <SPIFIFO.h>
#include "logTable.h"
#include "DAC8814.h"
#include "LTC2326_16.h"


/**************************************************************************/
/*
    Variable declarations
*/
/**************************************************************************/


// Scan parameters:
float lineRate = LINE_RATE; // Scan lines per second
unsigned int pixelsPerLine = IMAGE_PIXELS * 2;
unsigned int samplesPerPixel;
int scanSize = SCAN_SIZE; // Size of the scan in LSBs
int bias = BIAS; // Sample bias in LSBs
boolean scanningEnabled = false;
boolean engaged = false;


// Scan counters. Counts from -SCAN_COUNTER_LIMIT to SCAN_COUNTER_LIMIT - 1
// regardless of scan size, then counts back down when the scan direction reverses.
volatile int xCount = -SCAN_COUNTER_LIMIT; // X-axis scan counter
volatile int yCount = -SCAN_COUNTER_LIMIT; // Y-axis scan counter
volatile int dx = 0, dy = 0; // Scan counter increments


// Sample, pixel and line counters:
volatile unsigned int sampleCounter = 0, pixelCounter = 0, lineCounter = 0;
volatile int zAvg = 0, eAvg = 0; // Accumulates Z and error samples for later averaging


// Ping-pong buffers:
byte data1[DATA_BUFFER_LENGTH], data2[DATA_BUFFER_LENGTH]; // Data buffers
volatile boolean fillData1 = true; // Indicates which buffer to fill
volatile boolean sendData = false; // Indicates that data is ready to be sent over USB
boolean serialEnabled = false; // Enables serial transfer of data


// Position variables:
const int MAX_Z = (1 << (POSITION_BITS - 1)) - 1; // Maximum Z value
int xo = 0, yo = 0; // Scan offsets
volatile int x = 0, y = 0, z = 0; // Scanner coordinates in LSBs


// PI variables:
boolean pidEnabled = true; // Setting this to false desiables PI control
int setpoint = SETPOINT, setpointLog; // setpointLog = log(|setpoint|)
int Kp = KP, Ki = KI; // Proportional and integral gains
volatile int16_t input; // ADC input data
volatile int error = 0; // PID error signal
volatile int64_t iTerm = 0; // Integral term
const int64_t MAX_ITERM = MAX_Z * 0x100000000; // Maximum integral term. Used to prevent windup.


// Sigma-delta variables:
int sigmaX = 0, sigmaY = 0, sigmaZ = 0; // Sigma-delta integrators
const unsigned int shift = POSITION_BITS - DAC_BITS; // Number of bits to increase DAC resolution by using sigma-delta algorithm


// Timers:
IntervalTimer scanTimer;


// Data converters:
DAC8814 dac(CS_DAC, LDAC); // 16-bit quad DAC
LTC2326_16 adc(CS_ADC, CNV, BUSY); // 16-bit ADC
const int MAX_DAC_OUT = (1 << (DAC_BITS - 1)) - 1; // DAC upper bound
const int MIN_DAC_OUT = -(1 << (DAC_BITS - 1)); // DAC lower bound
boolean saturationCompensation = true; // The LTC2326-16 seems to output 0 when its input saturates. This is a temporary fix.


/**************************************************************************/
/*
    Setup
*/
/**************************************************************************/

void setup()
{
  pinMode(SERIAL_LED, OUTPUT);
  pinMode(TUNNEL_LED, OUTPUT);
  digitalWrite(SERIAL_LED, LOW);
  digitalWrite(TUNNEL_LED, LOW);

  // Set the sample bias:
  dac.begin();
  dac.setOutput((uint16_t)(bias + MAX_DAC_OUT + 1), DAC_CH_BIAS);
  
  setpointLog = logTable[abs(SETPOINT)]; // Take the log of the setpoint
  updateStepSizes(); // Compute the scan counter step sizes  
  adc.convert(); // Start an ADC conversion

  // Start the scan/PI/sigma-delta timer:
  scanTimer.priority(0);
  scanTimer.begin(incrementScan, dt);
}


/**************************************************************************/
/*
    Loop
*/
/**************************************************************************/

void loop()
{
  checkSerial(); // Check for incoming serial commands. See "SerialCommands" tab.
  
  // Illuminate tunelling LED if the tunneling current is > setpoint/2:
  if(abs(input) > setpoint >> 1) digitalWriteFast(TUNNEL_LED, HIGH);
  else digitalWriteFast(TUNNEL_LED, LOW);
  
  // Send data over USB if a line has been scanned and re-scanned:
  if(sendData)
  {    
    if(!fillData1) // Print data1
    {
      data1[0] = (byte)((lineCounter >> 8) & 0xFF); // High byte
      data1[1] = (byte)(lineCounter & 0xFF); // Low byte
      
      if(serialEnabled)
      {
        Serial.println("DATA");
        Serial.write(data1, DATA_BUFFER_LENGTH);
      }
      
      // Uncomment this block to print human-readable data to the serial port:
      /*
      for(unsigned int i = 0; i < pixelsPerLine * 2; i++) // Loop over pixels
      {
        Serial.print((int)((int)data1[4*i+2] << 24 | (int)data1[4*i+3] << 16 |(int)data1[4*i+4] << 8 |(int)data1[4*i+5]));
        Serial.print(" ");
      }
      */
    }
    else
    {
      data2[0] = (byte)((lineCounter >> 8) & 0xFF); // High byte
      data2[1] = (byte)(lineCounter & 0xFF); // Low byte
      
      if(serialEnabled)
      {
        Serial.println("DATA");
        Serial.write(data2, DATA_BUFFER_LENGTH);
      }
      
      // Uncomment this block to print human-readable data to the serial port:
      /*
      for(unsigned int i = 0; i < pixelsPerLine * 2; i++) // Loop over pixels
      {
        Serial.print((int)((int)data2[4*i+2] << 24 | (int)data2[4*i+3] << 16 |(int)data2[4*i+4] << 8 |(int)data2[4*i+5]));
        Serial.print(" ");
      }
      */     
    }
    Serial.println();
    
    sendData = false;
  }
}


/**************************************************************************/
/*
    Increment the scan, perform PI calculations, sigma-delta calculations,
    update the x, y and z DACs, store data in buffers.
*/
/**************************************************************************/

void incrementScan(void) // This interrupt runs in about ~18 us at 96 MHz
{  
  static int xout, yout, zout;
  static int64_t pTerm;
  
  //////////////////////////////////////////////////////////////////////
  // Increment the scan:
  //////////////////////////////////////////////////////////////////////
  
  if(scanningEnabled)
  {
    if(xCount <= -SCAN_COUNTER_LIMIT || xCount >= SCAN_COUNTER_LIMIT - 1 - dx) dx = -dx; // Reverse at the end of a line
    xCount += dx;
    x = (int)(((int64_t)xCount * (int64_t)scanSize) >> 31) + xo;
    if(yCount <= -SCAN_COUNTER_LIMIT || yCount >= SCAN_COUNTER_LIMIT - 1 - dy) dy = -dy; // Reverse and the end of a scan
    yCount += dy;
    y = (int)(((int64_t)yCount * (int64_t)scanSize) >> 31) + yo;
    if(yCount <= -SCAN_COUNTER_LIMIT) lineCounter = 0; // Just in case the scan and acquisition become desynchronized...
  }
  
  //////////////////////////////////////////////////////////////////////
  // Perform PI calculations:
  //////////////////////////////////////////////////////////////////////
  
  adc.begin(); // Set up the SPI port to communicate with the ADC
  input = adc.read(); // Read the ADC data over SPI
  if(saturationCompensation & (input == 0) & (z != -MAX_Z)) input = 32767; // Compensate for the LTC2326-16 saturation issue
  error = logTable[abs((int16_t)input)] - setpointLog; // Negative error = tip too far from sample
  
  if(pidEnabled)
  {
    pTerm = (int64_t)Kp * (int64_t)error;
    iTerm += (int64_t)Ki * (int64_t)error;
    if(iTerm > MAX_ITERM) iTerm = MAX_ITERM; // Constrain the integral term to prevent windup
    else if (iTerm < -MAX_ITERM) iTerm = -MAX_ITERM;
    z = (int)(((pTerm + iTerm) >> 32) & 0xFFFFFFFF);
    z = saturate(z, MAX_Z, -MAX_Z);
  }
  adc.convert(); // Initiate a new conversion. Data will be ready by the next time this interrupt runs.  
  
  
  //////////////////////////////////////////////////////////////////////
  // Perform sigma-delta calculations and update scanner DACs:
  //////////////////////////////////////////////////////////////////////
  
  dac.begin();
  xout = sigmaDelta(x, &sigmaX, shift);
  xout = saturate(xout, MAX_DAC_OUT, MIN_DAC_OUT);
  dac.setOutput((uint16_t)(xout + MAX_DAC_OUT + 1), DAC_CH_X);
  yout = sigmaDelta(y, &sigmaY, shift);
  yout = saturate(yout, MAX_DAC_OUT, MIN_DAC_OUT);
  dac.setOutput((uint16_t)(yout + MAX_DAC_OUT + 1), DAC_CH_Y);
  zout = sigmaDelta(z, &sigmaZ, shift);
  if(INVERT_Z) zout = -zout;
  zout = saturate(zout, MAX_DAC_OUT, MIN_DAC_OUT);
  dac.setOutput((uint16_t)(zout + MAX_DAC_OUT + 1), DAC_CH_Z);
  
  //////////////////////////////////////////////////////////////////////
  // Store data in buffer arrays and update counters:
  //////////////////////////////////////////////////////////////////////
  
  if(scanningEnabled)
  {
    zAvg += z; // Accumulate data for averaging
    eAvg += error;
    sampleCounter++;
    
    if(sampleCounter >= samplesPerPixel) // If enough samples have been acquired for one pixel
    {
      unsigned int indexZ = (pixelCounter << 2) + 2; // Index for Z data point in data buffer
      unsigned int indexE = indexZ + (pixelsPerLine << 2);  // Index for error data point in data buffer
      
      zAvg = zAvg / (int)samplesPerPixel; // Compute the average of acquired samples
      eAvg = eAvg / (int)samplesPerPixel;
            
      if(fillData1)
      {
        data1[indexZ]     = (byte)((zAvg >> 24) & 0xFF); // High byte Z
        data1[indexZ + 1] = (byte)((zAvg >> 16) & 0xFF);
        data1[indexZ + 2] = (byte)((zAvg >> 8) & 0xFF);
        data1[indexZ + 3] = (byte)(zAvg & 0xFF);         // Low byte Z
        data1[indexE]     = (byte)((eAvg >> 24) & 0xFF); // High byte E
        data1[indexE + 1] = (byte)((eAvg >> 16) & 0xFF);
        data1[indexE + 2] = (byte)((eAvg >> 8) & 0xFF);
        data1[indexE + 3] = (byte)(eAvg & 0xFF);         // Low byte E
      }
      else
      {
        data2[indexZ]     = (byte)((zAvg >> 24) & 0xFF); // High byte Z
        data2[indexZ + 1] = (byte)((zAvg >> 16) & 0xFF);
        data2[indexZ + 2] = (byte)((zAvg >> 8) & 0xFF);
        data2[indexZ + 3] = (byte)(zAvg & 0xFF);         // Low byte Z
        data2[indexE]     = (byte)((eAvg >> 24) & 0xFF); // High byte E
        data2[indexE + 1] = (byte)((eAvg >> 16) & 0xFF);
        data2[indexE + 2] = (byte)((eAvg >> 8) & 0xFF);
        data2[indexE + 3] = (byte)(eAvg & 0xFF);         // Low byte E
      }
      pixelCounter++;      
      sampleCounter = 0;
      zAvg = 0;
      eAvg = 0;
      
      if(pixelCounter >= pixelsPerLine)
      {
        pixelCounter = 0;
        fillData1 = !fillData1;
        sendData = true;
        lineCounter++;
        if(lineCounter >= pixelsPerLine)
          {
            lineCounter = 0;
          }
      }
    }
  }
}


/**************************************************************************/
/*
  Sigma delta. Used to produce a PWM output between LSBs of a DAC to 
  effectively increase its resolution. The DAC output must be low-pass 
  filtered to smooth out the PWM.
  
  Based on Tim Wescott's example here:
  http://www.embedded.com/design/configurable-systems/4006431/Sigma-delta-techniques-extend-DAC-resolution
*/
/**************************************************************************/

int sigmaDelta(int in, int *sigma, unsigned int shift)
{
  int out;
  
  *sigma += in; // Add desired input to sigma-delta integrator
  out = *sigma >> shift; // Truncate to the number of actual DAC bits
  *sigma -= out << shift; // Shift the DAC output value and subtract it from the integrator
  return out;
}
  
/**************************************************************************/
/*
  Saturate a value if it falls outside of max or min
*/
/**************************************************************************/

int saturate(int val, int max, int min)
{
  if(val > max) val = max;
  else if (val < min) val = min;
  return val;
}


/**************************************************************************/
/*
  This function updates scan stepsizes without changing the scan direction.
*/
/**************************************************************************/

void updateStepSizes()
{
  unsigned int new_samplesPerPixel = (unsigned int)(1000000.0f / (lineRate * (float)dt * (float)pixelsPerLine));
  int new_dx = (SCAN_COUNTER_LIMIT - 1)/ ((int)new_samplesPerPixel * (int)pixelsPerLine) * 4;
  int new_dy = new_dx / (int)pixelsPerLine;
  
  noInterrupts();
  samplesPerPixel = new_samplesPerPixel;
  if(dx > 0) dx = new_dx;
  else dx = -new_dx;
  if(dy > 0) dy = new_dy;
  else dy = -new_dy;
  interrupts();
}


/**************************************************************************/
/*
    Move the scanner to the scan start position.
*/
/**************************************************************************/

void resetScan()
{
  int xStart = -(scanSize >> 1) + xo;
  int yStart = -(scanSize >> 1) + yo;
  
  scanningEnabled = false; // disable scanning
  
  // Reset counters etc:
  noInterrupts();
  xCount = -SCAN_COUNTER_LIMIT;
  yCount = -SCAN_COUNTER_LIMIT;
  dx = 0;
  dy = 0;
  updateStepSizes(); // Re-calculate step sizes
  sampleCounter = 0;
  pixelCounter = 0;
  lineCounter = 0;
  zAvg = 0;
  eAvg = 0;
  fillData1 = true;
  interrupts();
  
  // Move to start position:
  moveTip(xStart, yStart);
}


/**************************************************************************/
/*
    Move from (x,y) to (xf,yf). The tip moves at the current scanning speed.
*/
/**************************************************************************/

void moveTip(int xf, int yf)
{
  int stepSize = abs((int)(((int64_t)dx * (int64_t)scanSize) >> 31));
  
  scanningEnabled = false;
  
  while (x > xf) {
    x -= stepSize;
    waitTimeStep(); // Wait for incrementScan() to update the DAC
  }
  while (x < xf) {
    x += stepSize;
    waitTimeStep();
  }
  while (y > yf) {
    y -= stepSize;
    waitTimeStep();
  }
  while (y < yf) {
    y += stepSize;
    waitTimeStep();
  }
}


/**************************************************************************/
/*
    Wait for on time interval dt.
*/
/**************************************************************************/

void waitTimeStep()
{
  unsigned int t = micros();
  while (micros() - t <= dt)
  {
    // Wait...
  }
}


/**************************************************************************/
/*
    Currently, this function only starts the scan and enables the Z feedback
    loop. For use with manual coarse approach. Will be replaced later with 
    a motorized approach function.
*/
/**************************************************************************/

boolean engage()
{
  scanningEnabled = true;
  engaged = true;
  pidEnabled = true;
  return true;
}


/**************************************************************************/
/*
    Retracts the scanner without using the approach motor. This function 
    only moves the scanner Z-axis, not the approach motor.
*/
/**************************************************************************/

void retract()
{

  scanningEnabled = false;
  pidEnabled = false;
  engaged = false;
  z = MAX_Z; // Fully retract the Z-piezo
  digitalWrite(TUNNEL_LED, LOW);
}


/**************************************************************************/
/*
    Engage the scanner without using the approach motor. This function 
    only moves the scanner Z-axis, not the approach motor. Returns true
    if the surface was detected, false otherwise. This function is not
    currently used.
*/
/**************************************************************************

boolean engageScanner()
{  
  if(!engaged)
  {
    pidEnabled = false;
    scanningEnabled = false;
    saturationCompensation = false;
  
    while (error < 0 && z > -MAX_Z)
    {
      z -= ENGAGE_SCANNER_STEP_SIZE;
      waitTimeStep();
    }
    
    // If scanner is not fully extended after approach, it has found the surface. Enable PID:
    if (z > -MAX_Z)
    {
      pidEnabled = true;
      engaged = true;
      saturationCompensation = true;
      digitalWrite(TUNNEL_LED, HIGH);
    }
    else // Fully retract the Z-piezo:
    {
      retract();
    }
  }
  return engaged;
}


/**************************************************************************/
/*
    Move the approach motor by the specified amount.
*/
/**************************************************************************

void stepMotor(int stepSize, int dir)
{
  
}

/**************************************************************************/
/*
  This function sweeps the bias voltage from its current value to minus its 
  current value while reading the current at every point.
*/
/**************************************************************************

void IVCurve()
{
  
}


/**************************************************************************/
/*
  This function retracts the Z-piezo by a specified distance while reading 
  the current at every point.
*/
/**************************************************************************

void IVCurve()
{
  
}


/***************************************************************/

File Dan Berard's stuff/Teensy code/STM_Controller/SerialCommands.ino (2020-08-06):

/**************************************************************************/
/*

Scanning Tunneling Microscope Feedback and Scan Controller for Teensy 3.X
Last updated Oct 14, 2015
http://dberard.com/home-built-stm/


 * Copyright (c) Daniel Berard, daniel.berard@mail.mcgill.ca
 *
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

This function reads incoming serial data and compares it to a list of 
commands used to control the microscope.

*/
/**************************************************************************/

void checkSerial()
{
  
  String serialString;
  
  if(Serial.available() > 0)
  {
    for(int i = 0; i < 2; i++)  // Accepts 2 char commands
    {
      delay(1); // This seems to be necessary, not sure why
      char inChar = Serial.read();
      serialString += inChar;
    }
  }
  serialCommand(serialString);
  serialString = "";
}

/**************************************************************************/

void serialCommand(String str)
{
  
  String command = "00";
  
  if (str.length() > 0)
  {     
      // Get the first 2 characters of str and store them in command:
      for(int i = 0; i < 2; i++)
      {
        command[i] = str[i];
      }
      
      
      if(command == "SE") // Enable serial communications
      {
        Serial.begin(115200);
        Serial.println("SE");
        serialEnabled = true;
        digitalWriteFast(SERIAL_LED, HIGH);
      }
      
      
      else if(command == "SD") // Disable serial communications
      {
        serialEnabled = false;
        Serial.flush();
        Serial.end();
        digitalWriteFast(SERIAL_LED, LOW);
      } 
      
      
      else if(command == "SS") // Scan size in LSBs
      {
        boolean scanningEnabledOnCommand = scanningEnabled;
        int new_scanSize = Serial.parseInt();
        int xNew, yNew;
        
        // Calculate position to move to:
        xNew = (int)(((float)(x - xo) * (float)new_scanSize) / (float)scanSize) + xo;
        yNew = (int)(((float)(y - yo) * (float)new_scanSize) / (float)scanSize) + yo;
        
        scanningEnabled = false; // Pause the scan
        
        if(new_scanSize > scanSize) // Update scanSize, then move
        {
          scanSize = new_scanSize;
          moveTip(xNew, yNew);
        }
        else // Move, then update scanSize
        {
          moveTip(xNew, yNew);
          scanSize = new_scanSize;
        }
        if(scanningEnabledOnCommand) scanningEnabled = true; // Resume scanning
      }
      
      
      else if(command == "IP") // Image pixels
      {        
        boolean scanningEnabledOnCommand = scanningEnabled;
        pixelsPerLine = Serial.parseInt() * 2;
        resetScan();
        if(scanningEnabledOnCommand) scanningEnabled = true;
      }
      
      
      else if(command == "LR") // Line rate in Hz
      {
        boolean scanningEnabledOnCommand = scanningEnabled;
        lineRate = (float)Serial.parseInt() / 100.0f; // Line rate is multiplied by 100 for the transmission
        while(pixelCounter != 0); // Wait for the scanner to finish scanning a line
        scanningEnabled = false; // Pause the scan
        updateStepSizes();
        if(scanningEnabledOnCommand) scanningEnabled = true; // Resume scan
      }
     
      
      else if(command == "XO") // X-offset
      {
        boolean scanningEnabledOnCommand = scanningEnabled;
        int previous_xo = xo;
        int new_xo = Serial.parseInt();
        scanningEnabled = false; // Pause the scan
        xo = new_xo;
        moveTip(x - previous_xo + xo, y); // Move over by (xo, yo)
        if(scanningEnabledOnCommand) scanningEnabled = true; // Resume scan
      } 
      
      
      else if(command == "YO") // Y-offset
      {
        boolean scanningEnabledOnCommand = scanningEnabled;
        int previous_yo = yo;
        int new_yo = Serial.parseInt();
        scanningEnabled = false;
        yo = new_yo;
        moveTip(x, y - previous_yo + yo);
        if(scanningEnabledOnCommand) scanningEnabled = true;
      } 
      
      
      else if(command == "SP") // Setpoint in LSBs
      {
        setpoint = Serial.parseInt();
        setpointLog = logTable[abs(setpoint)];       
      } 
      
      
      else if(command == "SB") // Sample bias in LSBs
      {
        bias = Serial.parseInt();
        noInterrupts();
        dac.setOutput((uint16_t)(bias + 32768), DAC_CH_BIAS); // Set the sample bias
        interrupts();          
      }
      
      
      else if(command == "KP") // P gain
      {
        Kp = Serial.parseInt();          
      } 
      
      
      else if(command == "KI") // I gain
      {
        Ki = Serial.parseInt() * dt;        
      }
      
      
      else if(command == "EN") // Enable scanning
      {
        resetScan();
        scanningEnabled = true; 
      } 
      
      
      else if(command == "DL") // Disable scanning
      {
        scanningEnabled = false;          
      } 
      
      
      else if(command == "TE") // Tip engage
      {        
        engage();          
      } 
      
      
      else if(command == "TR") // Tip retract
      {        
        retract();          
      }
  }
}

/**************************************************************************/

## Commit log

2020-07-09 Initial check-in
    [parts.xlsx, stm_power_supply.brd, stm_power_supply.sch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]
2020-08-07 added device photos

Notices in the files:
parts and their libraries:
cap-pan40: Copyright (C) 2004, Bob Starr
